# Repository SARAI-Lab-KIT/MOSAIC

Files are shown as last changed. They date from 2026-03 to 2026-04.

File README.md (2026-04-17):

# MOSAIC: A **M**odular **O**pen **S**ystem for **A**daptive **I**nteraction and **C**o-design


**MOSAIC** is a modular social robot platform for child-centered co-design with three different embodiments: a humanoid, an abstract, and a zoomorphic appearance. The embodiment is easily adaptable or extendable as it is 3D-printed and snaps on via a magnetic mechanism.

**MOSAIC** is designed as a dynamically evolving and openly accessible co-design toolkit for the community. We highly encourage anyone who is interested to use it as such, share their experiences, contribute to its further development, and thus help spread the practice of co-designing robots with their intended users. 

Embodiments2

ChatGPT Image Mar 29, 2026, 06_20_55 PM

This repository contains all the material related to the publication "MOSAIC: A reusable modular social robot platform for child-centered co-design".

## What you will find inside this repository
- **[hardware](https://github.com/SARAI-Lab-KIT/MOSAIC/tree/main/hardware)**: Hardware-related files, including all CAD files
- **[software](https://github.com/SARAI-Lab-KIT/MOSAIC/tree/main/software)**: Software-related files, including all scripts to test the included sensors, LEDs, ASR, dialog management, TTS
- **[videos](https://github.com/SARAI-Lab-KIT/MOSAIC/tree/main/videos)**: Videos showcasing the components of MOSAIC 

## Demos 
### Detecting user approaching
Approaching robot
### Detecting touch 
Touching robot
### Detecting robot movement 
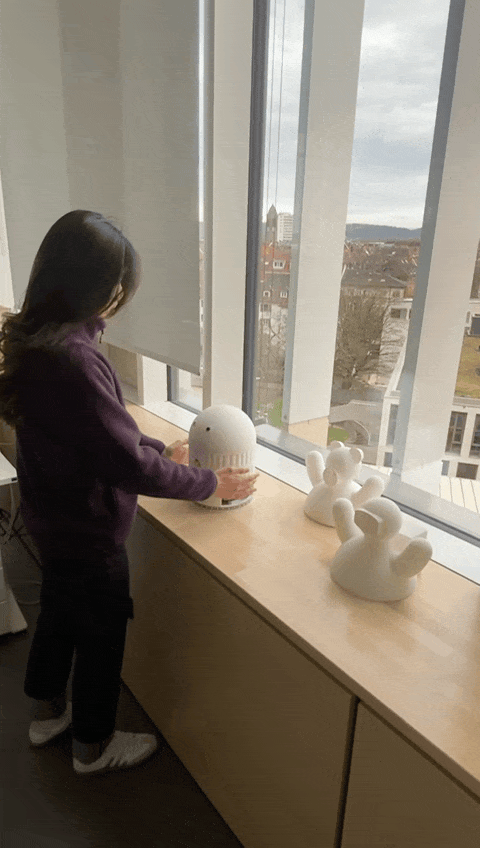
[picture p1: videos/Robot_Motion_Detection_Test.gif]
Moving robot

### Swapping embodiments 
Swapping body

## License
This repository is under the [GPL-3.0](https://github.com/SARAI-Lab-KIT/MOSAIC/blob/main/LICENSE) license.

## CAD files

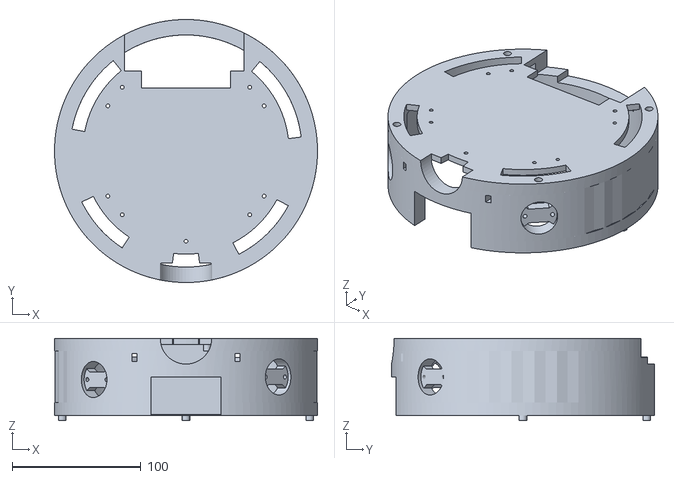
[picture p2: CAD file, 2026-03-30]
hardware/STL-files/Middle_Layer.stl
204.0 x 204.0 x 64.0

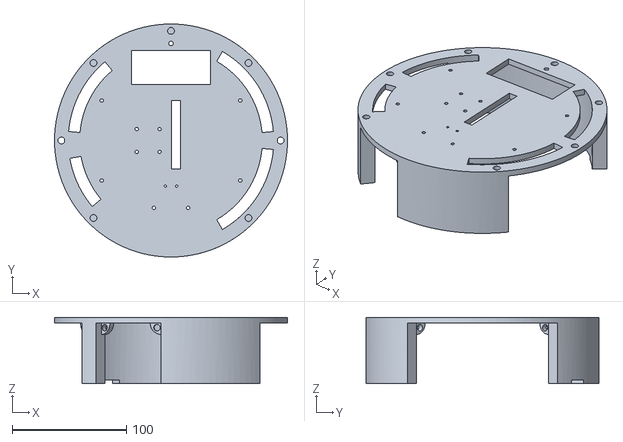
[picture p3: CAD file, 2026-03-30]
hardware/STL-files/Base_Layer_Wall.stl
204.0 x 204.0 x 58.0

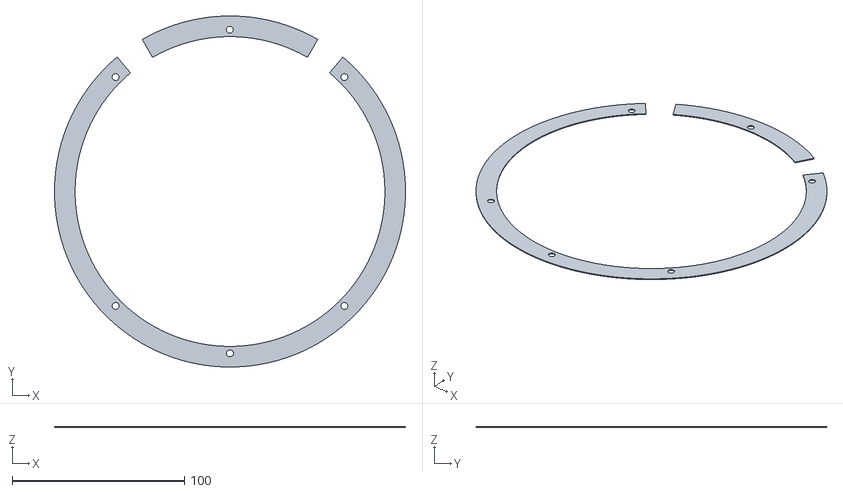
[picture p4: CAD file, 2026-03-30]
hardware/STL-files/LED_Strip_Cover.stl
204.0 x 203.9 x 0.5

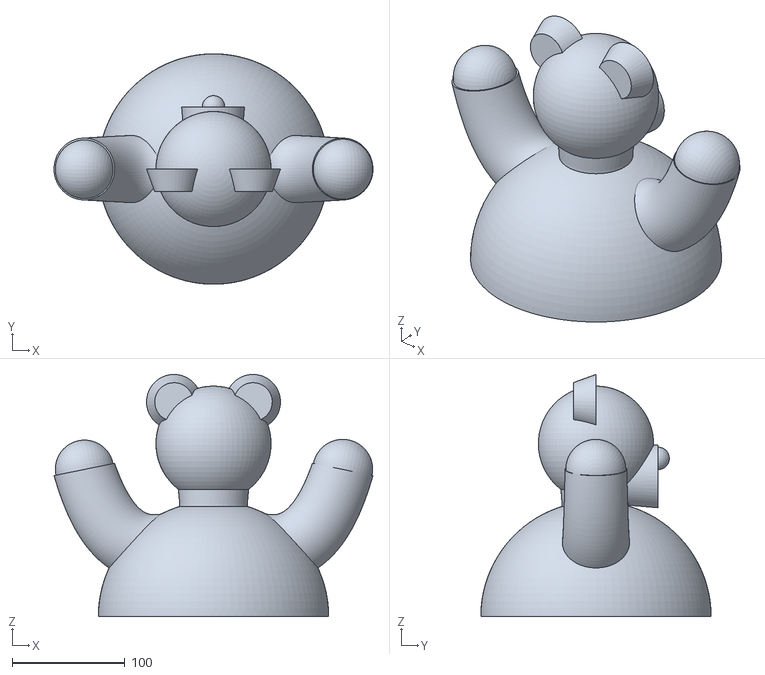
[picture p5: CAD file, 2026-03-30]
hardware/STL-files/Zoomorphic_Embodiment.stl
282.3 x 203.9 x 214.3

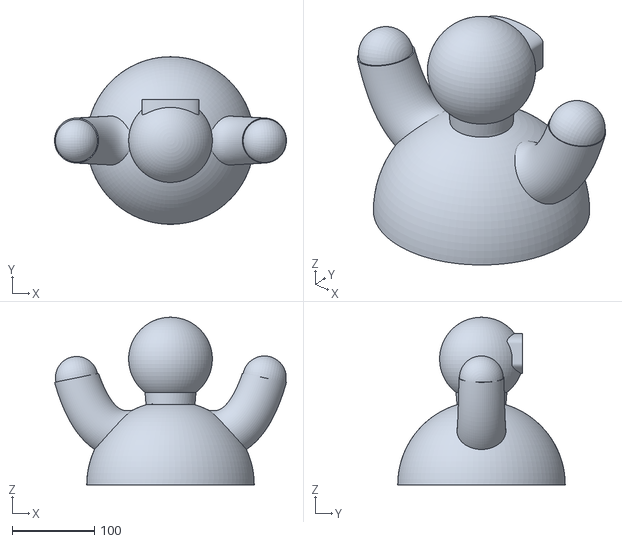
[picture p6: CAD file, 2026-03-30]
hardware/STL-files/Humanoid_Embodiment.stl
282.3 x 203.9 x 204.0

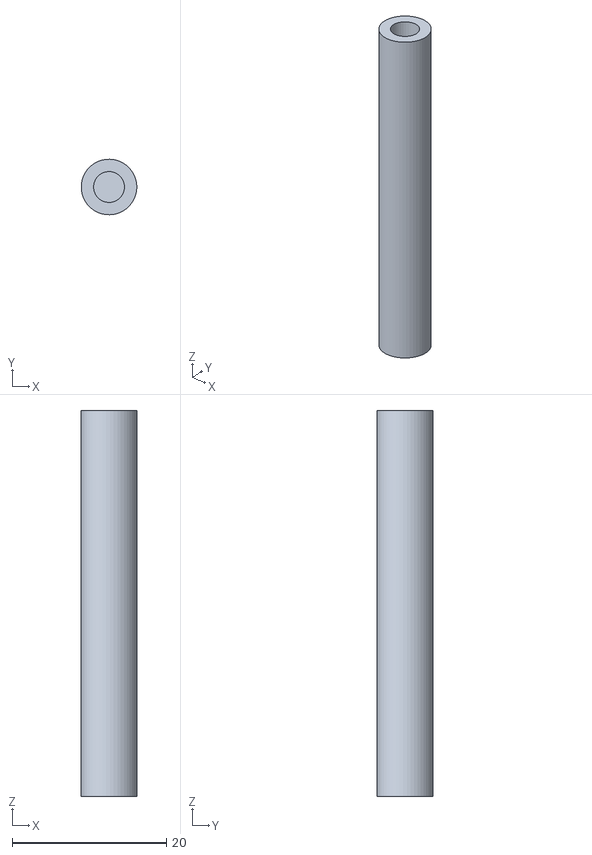
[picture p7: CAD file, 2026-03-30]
hardware/STL-files/Top_layer_attachment_Shafts.stl
7.19 x 7.20 x 50.0

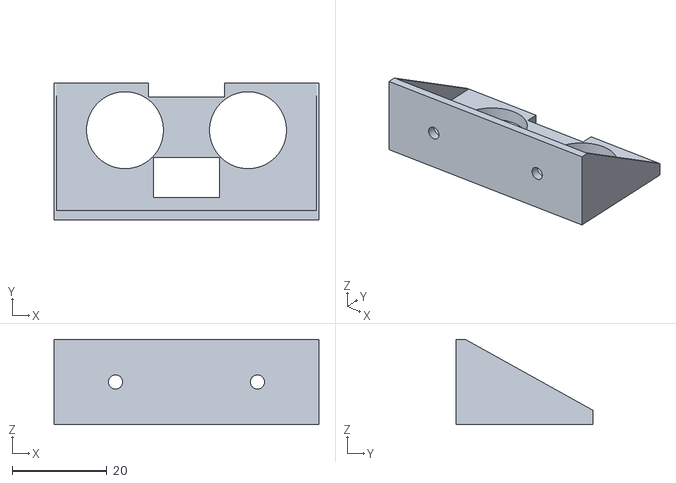
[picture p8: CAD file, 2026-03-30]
hardware/STL-files/Mount.stl
56.0 x 29.0 x 18.0

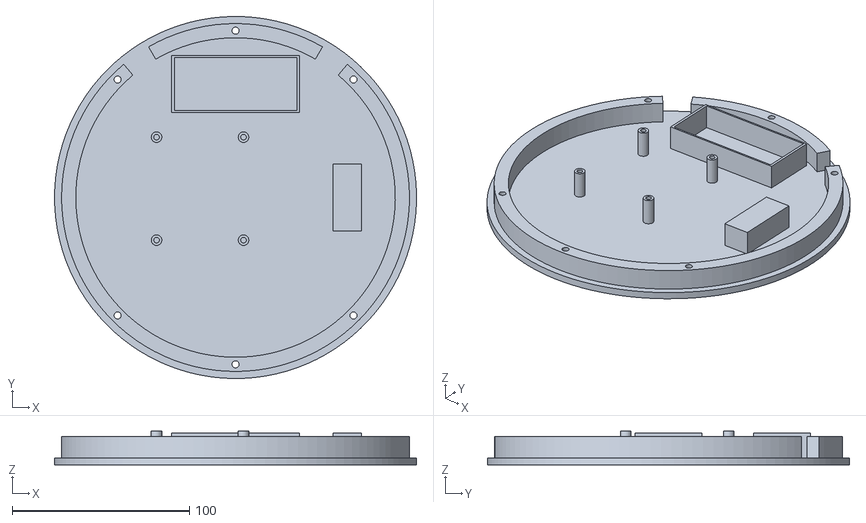
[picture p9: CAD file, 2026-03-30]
hardware/STL-files/Base_Layer.stl
204.0 x 204.0 x 19.0

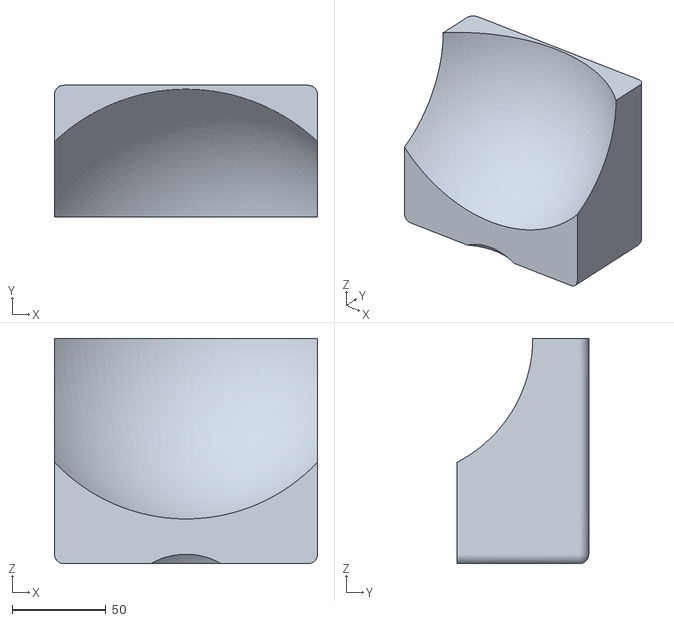
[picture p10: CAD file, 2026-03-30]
hardware/STL-files/Backpack.stl
140.0 x 70.0 x 120.0

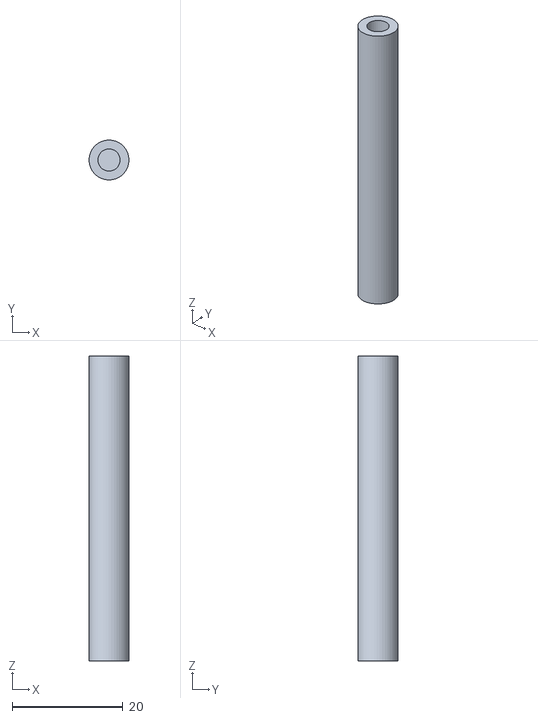
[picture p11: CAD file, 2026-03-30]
hardware/STL-files/Attachment_shaft.stl
7.19 x 7.20 x 55.0

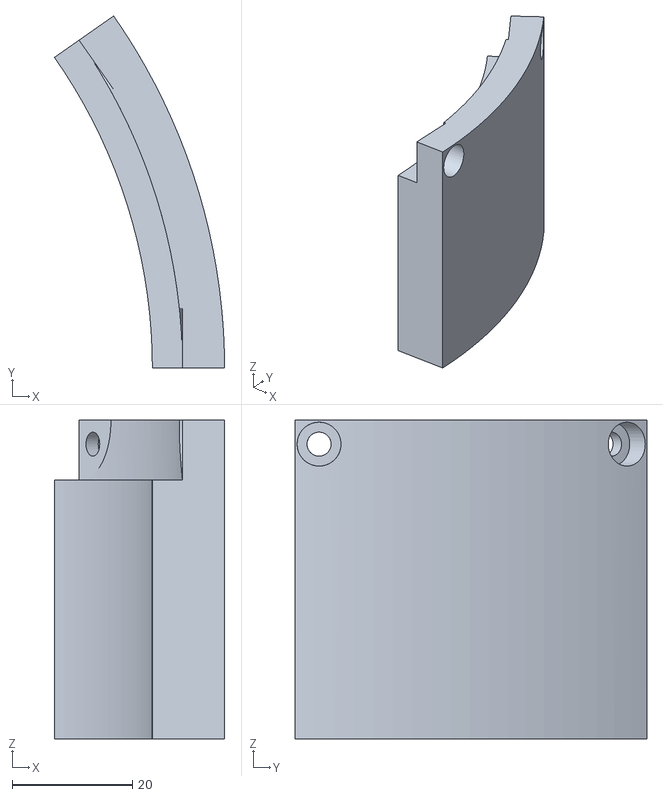
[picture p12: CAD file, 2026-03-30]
hardware/STL-files/Access_Panel_2.stl
28.3 x 58.5 x 53.0

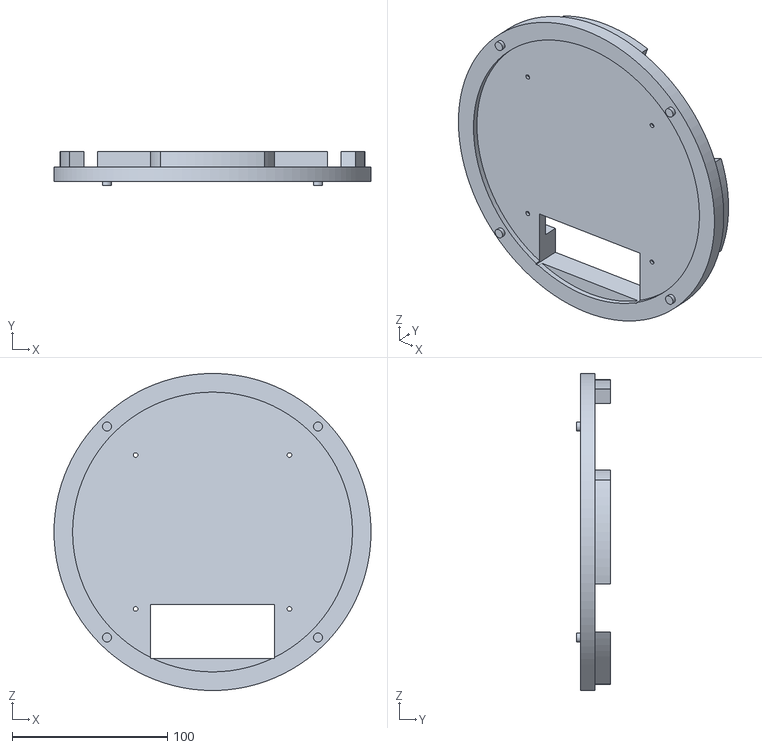
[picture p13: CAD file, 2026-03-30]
hardware/STL-files/Cover_Plate.stl
204.0 x 22.0 x 204.0

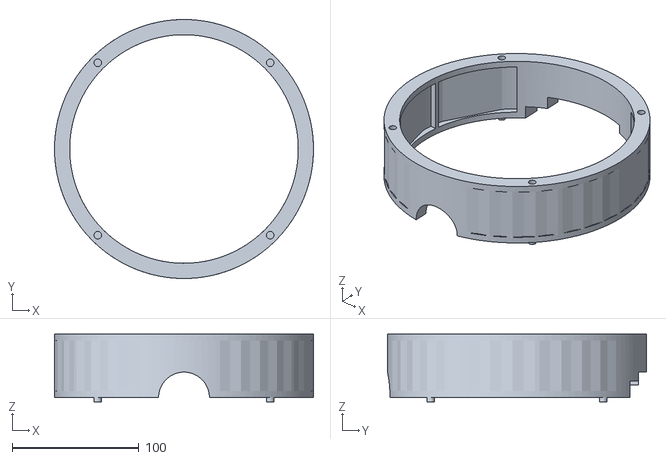
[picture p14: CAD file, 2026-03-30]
hardware/STL-files/Top_layer_Wall.stl
204.0 x 204.0 x 53.5

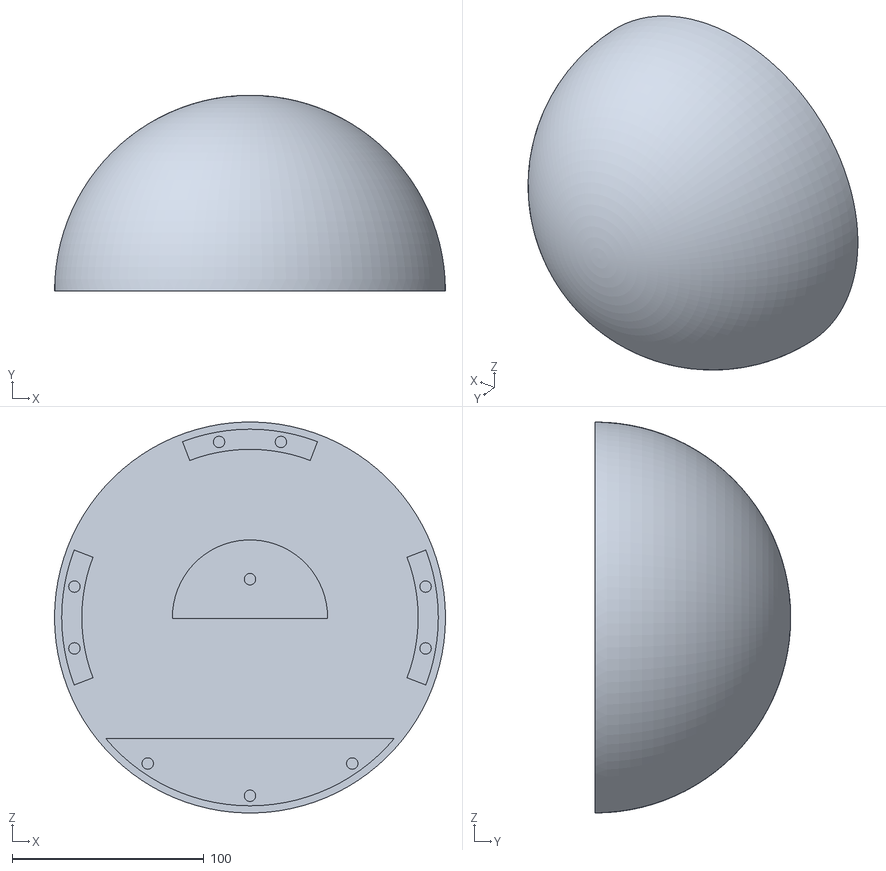
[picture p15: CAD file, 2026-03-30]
hardware/STL-files/Abstract_Embodiment.stl
204.0 x 102.0 x 203.9

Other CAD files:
hardware/STL-files/Access_Panel_1.stl
hardware/CAD-files-Fusion360/Abstract_Embodiment.f3d
hardware/CAD-files-Fusion360/Access_Panel_1.f3d
hardware/CAD-files-Fusion360/Access_Panel_2.f3d
hardware/CAD-files-Fusion360/Attachment_shaft.f3d
hardware/CAD-files-Fusion360/Backpack.f3d
hardware/CAD-files-Fusion360/Base_Layer.f3d
hardware/CAD-files-Fusion360/Base_Layer_Wall.f3d
hardware/CAD-files-Fusion360/Cover_Plate.f3d
hardware/CAD-files-Fusion360/Humanoid_Embodiment.f3d
hardware/CAD-files-Fusion360/LED_Strip_Cover.f3d
hardware/CAD-files-Fusion360/Middle_Layer.f3d
hardware/CAD-files-Fusion360/Mount.f3d
hardware/CAD-files-Fusion360/Top_layer_Wall.f3d
hardware/CAD-files-Fusion360/Top_layer_attachment_Shafts.f3d
hardware/CAD-files-Fusion360/Zoomorphic_Embodiment.f3d

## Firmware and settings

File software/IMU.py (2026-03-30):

#!/usr/bin/env python3
import time
import math
import board
import neopixel
import qwiic_icm20948

# -----------------------------
# LED configuration
# -----------------------------

STRIP_NUM = 30
RING_NUM = 16

strip = neopixel.NeoPixel(board.D19, STRIP_NUM, brightness=0.3, auto_write=False)
ring1 = neopixel.NeoPixel(board.D18, RING_NUM, brightness=0.3, auto_write=False)
ring2 = neopixel.NeoPixel(board.D13, RING_NUM, brightness=0.3, auto_write=False)

# -----------------------------
# IMU Setup
# -----------------------------

imu = qwiic_icm20948.QwiicIcm20948()

if not imu.connected:
    print("IMU not detected")
    exit()

imu.begin()
print("IMU initialized")


ACCEL_THRESHOLD = 10000
GYRO_THRESHOLD = 1200


def vec_delta(a,b):
    return math.sqrt((b[0]-a[0])**2 + (b[1]-a[1])**2 + (b[2]-a[2])**2)


def flash_blue():

    for _ in range(3):

        strip.fill((0,0,255))
        ring1.fill((0,0,255))
        ring2.fill((0,0,255))

        strip.show()
        ring1.show()
        ring2.show()

        time.sleep(0.15)

        strip.fill((0,0,0))
        ring1.fill((0,0,0))
        ring2.fill((0,0,0))

        strip.show()
        ring1.show()
        ring2.show()

        time.sleep(0.15)


# initial sample
while not imu.dataReady():
    time.sleep(0.01)

imu.getAgmt()

prev_accel = (imu.axRaw, imu.ayRaw, imu.azRaw)
prev_gyro = (imu.gxRaw, imu.gyRaw, imu.gzRaw)


print("Move the robot to test pickup detection")

while True:

    if imu.dataReady():

        imu.getAgmt()

        accel = (imu.axRaw, imu.ayRaw, imu.azRaw)
        gyro = (imu.gxRaw, imu.gyRaw, imu.gzRaw)

        d_accel = vec_delta(prev_accel, accel)
        d_gyro = vec_delta(prev_gyro, gyro)

        if d_accel > ACCEL_THRESHOLD or d_gyro > GYRO_THRESHOLD:

            print("Robot moved")
            flash_blue()

        prev_accel = accel
        prev_gyro = gyro

    time.sleep(0.05)

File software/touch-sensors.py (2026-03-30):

#!/usr/bin/env python3
import time
import spidev
import board
import neopixel

# -----------------------------
# LED setup
# -----------------------------

STRIP_NUM = 30
RING_NUM = 16

strip = neopixel.NeoPixel(board.D19, STRIP_NUM, brightness=0.3, auto_write=False)
ring1 = neopixel.NeoPixel(board.D18, RING_NUM, brightness=0.3, auto_write=False)
ring2 = neopixel.NeoPixel(board.D13, RING_NUM, brightness=0.3, auto_write=False)

LEFT_RANGE = range(0, STRIP_NUM//2)
RIGHT_RANGE = range(STRIP_NUM//2, STRIP_NUM)

# -----------------------------
# MCP3008 setup
# -----------------------------

spi = spidev.SpiDev()
spi.open(0,0)
spi.max_speed_hz = 1350000

# -----------------------------
# Piezo channel mapping
# -----------------------------

LEFT_CHANNELS = [0,2]
RIGHT_CHANNELS = [1,4,3]

THRESHOLD = 10
COOLDOWN = 0.25

# -----------------------------
# ADC read
# -----------------------------

def read_adc(ch):
    adc = spi.xfer2([1,(8+ch)<<4,0])
    return ((adc[1]&3)<<8) + adc[2]

# -----------------------------
# LED helpers
# -----------------------------

def clear_leds():
    strip.fill((0,0,0))
    ring1.fill((0,0,0))
    ring2.fill((0,0,0))

    strip.show()
    ring1.show()
    ring2.show()


def flash_left():

    strip.fill((0,0,0))

    for i in LEFT_RANGE:
        strip[i] = (255,0,0)

    ring1.fill((255,0,0))

    strip.show()
    ring1.show()

    time.sleep(0.2)
    clear_leds()


def flash_right():

    strip.fill((0,0,0))

    for i in RIGHT_RANGE:
        strip[i] = (255,0,0)

    ring2.fill((255,0,0))

    strip.show()
    ring2.show()

    time.sleep(0.2)
    clear_leds()


def flash_all():

    strip.fill((255,0,0))
    ring1.fill((255,0,0))
    ring2.fill((255,0,0))

    strip.show()
    ring1.show()
    ring2.show()

    time.sleep(0.2)
    clear_leds()


# -----------------------------
# Initial baselines
# -----------------------------

channels = LEFT_CHANNELS + RIGHT_CHANNELS
prev_vals = {ch: read_adc(ch) for ch in channels}

last_event = 0

print("5 piezo sensors active (3 left / 2 right)")

# -----------------------------
# Main loop
# -----------------------------

while True:

    now = time.time()

    vals = {ch: read_adc(ch) for ch in channels}

    left_hit = False
    right_hit = False

    for ch in LEFT_CHANNELS:
        if abs(vals[ch] - prev_vals[ch]) > THRESHOLD:
            left_hit = True

    for ch in RIGHT_CHANNELS:
        if abs(vals[ch] - prev_vals[ch]) > THRESHOLD:
            right_hit = True

    if (now - last_event) > COOLDOWN:

        if left_hit and right_hit:
            print("BOTH SIDES TOUCH")
            flash_all()
            last_event = now

        elif left_hit:
            print("LEFT TOUCH")
            flash_left()
            last_event = now

        elif right_hit:
            print("RIGHT TOUCH")
            flash_right()
            last_event = now

    prev_vals = vals

    time.sleep(0.002)

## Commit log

2026-03-30 Initial commit of hardware, software and video files
    [Abstract_Embodiment.f3d, Abstract_Embodiment.stl, Access_Panel_1.f3d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]
2026-03-30 Adding gifs for demos of sensors and swapping embodiments
2026-04-02 Add offline multilingual voice assistant script
    This script implements an offline multilingual voice assistant for Raspberry Pi, featuring microphone capture, speech-to-text, dialog management, and text-to-speech functionalities.

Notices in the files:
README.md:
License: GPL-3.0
